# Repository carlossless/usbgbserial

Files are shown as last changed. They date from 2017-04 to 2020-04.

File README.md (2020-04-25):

# usbgbserial

> ⚠️ This project is very much work in progress. Most things are either not done or don't fully work. ⚠️

usbgbserial

A USB to [Game Link Cable](https://en.wikipedia.org/wiki/Game_Link_Cable) interface.

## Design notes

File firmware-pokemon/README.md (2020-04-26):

# usbgbserial-pokemon

This is firmware for [usbgbserial](http://github.com/carlossless/usbgbserial) to simulate Pokemon Gen2 JP (Silver, Gold, Crystal) trades with a real GameBoy acting as player 1 (internal clock) and usbgbserial acting as player 2 (external clock).

The main parts of the protocol have been figured out thanks to [Bulbapedia](https://bulbapedia.bulbagarden.net/wiki/Pok%C3%A9mon_data_structure_in_Generation_II), the [Pokemon Crystal Disassembly](https://github.com/pret/pokecrystal) and some trial and error with a logic analyzer. However, there are still quite a few nuances of the pokemon trade center protocol that are not handled by this software.

All of the communication and trade-simulation is done on the atmega32u2 and does not require use of a connected USB host (PC) to usbgbserial.

## Video

usbgbserial-pokemon (https://youtu.be/4CrVcxVYpOA)

## TODOs

* Use AVR SPI peripheral for the link protocol instead of single I/O pin interrupts. (requires board change)
* Implement a timeout for when a player exits the trade room and reset back to the `NOT_CONNECTED` state.

## References

* [SameBoy](https://sameboy.github.io/) - a cross-platform DMG/GBC emulator that works great on macOS.
* [Bulbapedia](https://bulbapedia.bulbagarden.net/wiki/Pok%C3%A9mon_data_structure_in_Generation_II) - full documentation on the 48byte data structure that is used to store pokemon data in Gen2 games.
* [github.com/pret/pokecrystal](https://github.com/pret/pokecrystal) - ongoing project to create a readable disassembly of Pokemon Crystal.
* [Spoofing Pokémon trades with the Stellaris LaunchPad](http://www.adanscotney.com/2014/01/spoofing-pokemon-trades-with-stellaris.html) - another project that uses a TI Stellaris LaunchPad to spoof Pokemon Gen1 Trades.

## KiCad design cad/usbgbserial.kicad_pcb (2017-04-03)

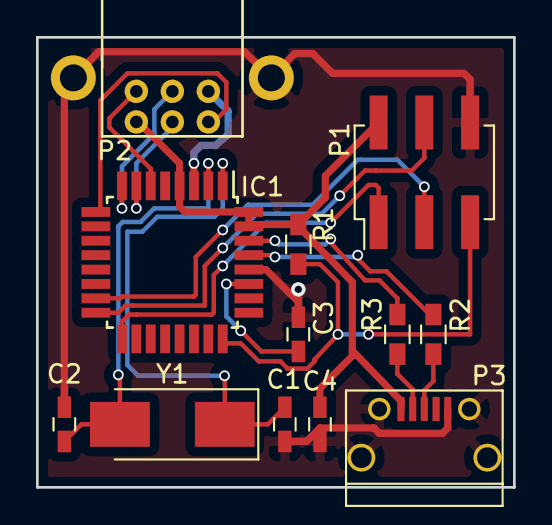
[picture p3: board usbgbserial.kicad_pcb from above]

Board: 2 copper layers, 26.5 x 25.0 mm, 12 parts (0 on the bottom side), 17 nets.

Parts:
C1, C2: 22pF; C_0603_HandSoldering
C3: 1uF; C_0603_HandSoldering
C4: 100nF; C_0603_HandSoldering
IC1: ATMEGA32U2; TQFP-32_7x7mm_Pitch0.8mm
P1: AVR_ISP; Pin_Header_Straight_2x03_Pitch2.54mm_SMD
P2: GB_SERIAL; gb-serial
P3: USB_OTG; USB_Micro-B
R1: 10K; R_0603_HandSoldering
R2, R3: 22; R_0603_HandSoldering
Y1: 16Mhz; Crystal_SMD_0603-2pin_6.0x3.5mm_HandSoldering

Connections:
GND: C1.2, C2.2, C3.2, C4.2, IC1.3, IC1.28, P1.6, P2.6, P2.7, P3.5, P3.6
MISO: IC1.17, P1.1
MOSI: IC1.16, P1.4
unnamed: C1.1, IC1.1, Y1.1
unnamed: C2.1, IC1.2, Y1.2
unnamed: C3.1, IC1.27
unnamed: IC1.6, P2.2
unnamed: IC1.7, P2.3
unnamed: IC1.8, P2.4
unnamed: IC1.9, P2.5
unnamed: IC1.29, R2.1
unnamed: IC1.30, R3.1
unnamed: P3.2, R3.2
unnamed: P3.3, R2.2
RESET: IC1.24, P1.5, R1.1
SCK: IC1.15, P1.3
VCC: C4.1, IC1.4, IC1.31, IC1.32, P1.2, P2.1, P3.1, R1.2

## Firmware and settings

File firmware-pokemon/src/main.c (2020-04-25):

#include <stdint.h>
#include "gbserial.h"
#include "utils.h"
#include "pokemon_payload.h"

#define POKEMON_PLAYER_ONE 0x01
#define POKEMON_PLAYER_TWO 0x02

#define POKEMON_TRADE_CENTER_SELECTION 0xD1

#define POKEMON_TRANSFER_PREAMBLE 0xfd

#define POKEMON_TRADE_CANCELED 0x7F
#define POKEMON_TRADE_ACCEPT 0x72

#define NAME_LENGTH 6
#define POKEMON_NAME_LENGTH 11
#define MAX_POKEMON_COUNT 6
#define POKEMON_COUNT 3

#define TRAINER_ID \
  {                \
    0xde, 0xad     \
  }

const uint8_t trainer_id[2] = TRAINER_ID;

// https://github.com/pret/pokecrystal/blob/master/charmap.asm#L409-L418
uint8_t trainer_name[NAME_LENGTH] = {0xf7, 0xf9, 0xf9, 0xfd, 0x50, 0x50}; // 1337 in the japaneese charmap
uint8_t pokemon_name[NAME_LENGTH] = {0xf7, 0xf9, 0xf9, 0xfd, 0x50, 0x50};
uint8_t original_trainer_name[NAME_LENGTH] = {0xf7, 0xf9, 0xf9, 0xfd, 0x50, 0x50};

const pokemon_payload mew = {
    .species = 0x97,                   // Mew
    .held_item = 0x01,                 // Master Ball
    .moves = {0x25, 0x37, 0x38, 0x26}, // Mega Kick, Thrash, Double Edge, Jump Kick
    .trainer_id = TRAINER_ID,
    .experience = 1059860,
    .hp_ev = 0,
    .attack_ev = 0,
    .defense_ev = 0,
    .speed_ev = 0,
    .special_ev = 0,
    .iv = 0,
    .move_pps = {20, 25, 5, 15}, // 20/20, 25/25, 5/5, 15/15
    .friendship = 80,
    .pokerus = 0,
    .caught_data = 0,
    .level = 100,
    .status = 0, // Normal
    .unused = 0,
    .hp = 256,
    .max_hp = 256,
    .attack = 256,
    .defense = 256,
    .speed = 256,
    .special_attack = 256,
    .special_defense = 256};

typedef enum
{
  NOT_CONNECTED,
  CONNECTED,
  IN_TRADE_CENTER,
  TRADE_SELECTION,
  TRADE_CONFIRMATION,
  TRADE_FINALIZATION
} t_state;

t_state state = NOT_CONNECTED;

void connect()
{
  uint8_t input;

  // get input byte. it will always be 0x01 (player 1) since we're using the gameboy (player 1) clock
  gbserial_receive(&input);
  if (input == POKEMON_PLAYER_ONE)
  {
    // we respond with 0x02 (player 2), since we're using the external clock from player 1
    gbserial_send(POKEMON_PLAYER_TWO);
  }

  // two 0x00 sent afterwards
  pad_with_zeroes(2);

  state = CONNECTED;
}

void enter_trade_center()
{
  uint8_t input;

  // one 0x00 padding.
  gbserial_receive(&input);

  // 0x62 -- unknown
  repeat_values(0x62, 13);

  pad_with_zeroes(10);

  gbserial_receive(&input);
  if (input == POKEMON_TRADE_CENTER_SELECTION)
  {
    gbserial_send(POKEMON_TRADE_CENTER_SELECTION);
  }

  pad_with_zeroes(2);

  state = IN_TRADE_CENTER;
}

void trade_initiated()
{
  uint8_t input;

  // 0x00 - one blank byte
  gbserial_receive(&input);

  // 0x75 - 13 bytes
  repeat_values(0x75, 13);
  pad_with_zeroes(9);

  // 0x00 - one blank byte
  pad_with_zeroes(1);

  // 0x76 - 13 bytes
  repeat_values(0x76, 13);

  // 0x00 - 12 bytes
  for (int i = 0; i < 12; i++)
  {
    gbserial_receive(&input);
  }

  // 0xfd - 9 bytes
  repeat_values(POKEMON_TRANSFER_PREAMBLE, 9);

  gbserial_receive(&input); // first byte of random data

  // mirror 10 bytes of random data
  for (int i = 0; i < 10; i++)
  {
    gbserial_transceive(input, &input);
  }

  // 0xfd - 9 bytes
  repeat_values(POKEMON_TRANSFER_PREAMBLE, 9);

  // trainer name - 6 bytes
  send_bytes(trainer_name, NAME_LENGTH);

  // number of pokemon in party - 1 byte
  gbserial_send(POKEMON_COUNT);

  // party pokemon species - 6 bytes + 1 byte
  for (int i = 0; i < POKEMON_COUNT; i++)
  {
    gbserial_send(mew.species); // all mews
  }
  gbserial_send(0xff);                                // end
  pad_with_zeroes(MAX_POKEMON_COUNT - POKEMON_COUNT); // pad the rest

  // trainer id - 2 bytes
  send_bytes((uint8_t *)&trainer_id, 2);

  // pokemons structs - 6 * 48 = 288 bytes
  for (int i = 0; i < POKEMON_COUNT; i++)
  {
    send_bytes((uint8_t *)&mew, POKEMON_PAYLOAD_SIZE);
  }
  pad_with_zeroes((MAX_POKEMON_COUNT - POKEMON_COUNT) * POKEMON_PAYLOAD_SIZE); // pad the rest

  // original trainer names - 36 bytes
  for (int i = 0; i < POKEMON_COUNT; i++)
  {
    send_bytes(original_trainer_name, NAME_LENGTH);
  }
  pad_with_zeroes((MAX_POKEMON_COUNT - POKEMON_COUNT) * NAME_LENGTH);

  // pokemon names - 36 bytes
  for (int i = 0; i < POKEMON_COUNT; i++)
  {
    send_bytes(pokemon_name, NAME_LENGTH); // check
  }
  pad_with_zeroes((MAX_POKEMON_COUNT - POKEMON_COUNT) * NAME_LENGTH); // check

  // unkown region of payload
  pad_with_zeroes(7);

  repeat_values(0xfd, 6);

  pad_with_zeroes(7);

  // end transfer 0xff
  repeat_values(0xff, 2);

  // unkown region of payload
  pad_with_zeroes(446);

  gbserial_send(0xff);

  pad_with_zeroes(30);

  // payload ended

  state = TRADE_SELECTION;
}

void trade_selection()
{
  uint8_t input;

  // 0x00
  gbserial_receive(&input);

  // first real byte - selected pokemon or trade canceled
  gbserial_receive(&input);
  if (input >= 0x70 && input <= 0x75) // any available pokemons selected
  {
    repeat_values(0x70, 13); // first pokemon selected
    state = TRADE_CONFIRMATION;
  }
  else if (input == POKEMON_TRADE_CANCELED)
  {
    repeat_values(POKEMON_TRADE_CANCELED, 13); // confirm cancelation
    state = IN_TRADE_CENTER;
  }
  else
  {
    // unexpected state
  }

  pad_with_zeroes(9);
}

void trade_confirmation()
{
  uint8_t input;

  // 0x00
  gbserial_receive(&input);

  // first real byte - confirmed or canceled
  gbserial_receive(&input);
  if (input == POKEMON_TRADE_ACCEPT) // trade has been accepted
  {
    repeat_values(POKEMON_TRADE_ACCEPT, 13); // accept trade
    state = TRADE_FINALIZATION;
  }
  else if (input == 0x71) // trade has been declined
  {
    repeat_values(0x71, 13); // also decline trade (value probably doesn't matter here)
    state = TRADE_SELECTION;
  }
  else
  {
    // unexpected state
  }

  pad_with_zeroes(9);
}

void trade_finalization()
{
  uint8_t input;

  // 0x00
  gbserial_receive(&input);

  gbserial_receive(&input);
  if (input == 0x71) // trade finalized (animation finished)
  {
    repeat_values(0x71, 13); // also finalize (value probably doesn't matter here)
    state = IN_TRADE_CENTER;
  }
  else
  {
    // unexpected state
  }

  pad_with_zeroes(9);
}

int main(void)
{
  gbserial_init();

  while (1)
  {
    switch (state)
    {
    case NOT_CONNECTED:
      connect();
      break;
    case CONNECTED:
      enter_trade_center();
      break;
    case IN_TRADE_CENTER:
      trade_initiated();
      break;
    case TRADE_SELECTION:
      trade_selection();
      break;
    case TRADE_CONFIRMATION:
      trade_confirmation();
      break;
    case TRADE_FINALIZATION:
      trade_finalization();
      break;
    default:
      break;
    }
  }

  return 0;
}

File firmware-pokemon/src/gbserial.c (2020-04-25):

#include "gbserial.h"
#include <avr/interrupt.h>
#include <avr/sfr_defs.h>

// Connections:
// GB Link Cable | AVR PIN | AVR INT
// --------------+---------+--------
// GBSO          | PD0     | INT0
// GBSI          | PD1     | INT1
// GBSR          | PD2     | INT2
// GBSC          | PD3     | INT3

#define bit_get(p, m) ((p) & (m))
#define bit_set(p, m) ((p) |= (m))
#define bit_clear(p, m) ((p) &= ~(m))
#define bit_flip(p, m) ((p) ^= (m))
#define bit_write(c, p, m) (c ? bit_set(p, m) : bit_clear(p, m))

#define gbserial_read_bit(r, p, b) b |= bit_get(r, _BV(p)) >> p
#define gbserial_write_bit(r, p, b) bit_write((b & 0b10000000) >> 7, r, _BV(p))

volatile uint8_t gb_bit = 0; // current_bit
volatile uint8_t gb_sin = 0;
volatile uint8_t gb_sout = 0;

// falling edge interupt
ISR(INT3_vect)
{
  gbserial_read_bit(PIND, 1, gb_sin);
  gbserial_write_bit(PORTD, 0, gb_sout);

  gb_bit++;
  if (gb_bit < 8)
  {
    gb_sin <<= 1;
    gb_sout <<= 1;
  }
}

void gbserial_init()
{
  DDRD = 0b00000001;  // PD3/INT3 = INPUT, PD2 = N/A, PD1 = INPUT, PD0 = OUTPUT.
  PORTD = 0b00001111; // set internal pullups for all inputs.

  EICRA = 0b10000000; // ISC31 = 1, ISC30 = 0, falling edge of INT3 generates the interupt.
  EIMSK = 0b00001000; // enable INT3 interupt.
}

void gbserial_transceive(uint8_t input, uint8_t *output)
{
  gb_bit = 0;
  gb_sin = 0;
  gb_sout = input;

  sei();
  while (1)
  {
    if (gb_bit > 7)
    {
      break;
    }
  }
  cli();
  *output = gb_sin;
}

void gbserial_transceive_bytes(uint8_t *input, uint8_t *output, int length)
{
  for (int i = 0; i < length; i++)
  {
    gbserial_transceive(input[i], &output[i]);
  }
}

void gbserial_send(uint8_t input)
{
  uint8_t tmp;
  gbserial_transceive(input, &tmp);
}

void gbserial_receive(uint8_t *output)
{
  gbserial_transceive(0x00, output);
}

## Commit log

2017-04-03 First PCB version
    [usbgbserial.kicad_pcb, usbgbserial.sch]
2020-04-26 switched video iframe with link
